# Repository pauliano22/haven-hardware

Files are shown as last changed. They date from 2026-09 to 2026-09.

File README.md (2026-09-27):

# haven-hardware

Hardware design files for Project Haven. All binary CAD/PCB formats
(`.step`, `.stp`, `.stl`, `.epro`, `.xlsx`, `.pdf`, and Altium library files)
are tracked via **Git LFS** — run `git lfs install` once, then clone
normally.

## Layout

- **`openearable_base_pcb/`** — OpenEarable's official PCB exports as
  downloaded from Altium 365: main 2.0, flex 2.0, and a debugging breakout
  1.0. Each folder has schematic/layout PDFs, a BOM, and an `.epro` (Altium
  365 packaged release — open it via Altium 365's viewer or import into
  Altium Designer). No raw `.PcbDoc`/`.SchDoc` source is included upstream.
- **`mechanical_cad/`** — Enclosure CAD. `OpenEarable-Enclosure-2.0.1/` is
  the upstream OpenEarable reference (front/back shells, speaker mount,
  battery mount, `.step` + `.stl`). `Enclosure.stp` is Haven's own enclosure
  design.
- **`haven_dev_board/`** — Haven's own stripped-down custom dev board.
  `component_libraries/` holds Ultra Librarian Altium parts (symbol +
  footprint + 3D model) for the ADAU1860 DSP and the SPH0645LM4H-B MEMS mic.
  **Mic caveat (2026-09-10):** the SPH0645LM4H-B is an *I2S* microphone. On
  the OpenEarable-derived board the mic (SPH0641LU4H-1) is a *PDM* part wired
  straight into the ADAU1860's DMIC pins (netlist: U13 → `PDMCLK`/`PDMDIN` →
  U15 C4/C5), and the codec — not the nRF5340 — owns the mic → DSP → speaker
  path. A stripped-down dev board that keeps that topology needs a PDM mic
  library part (e.g. SPH0641LU4H-1), not the I2S one here. See
  `haven-dev-board-kicad/HAVEN_HARDWARE_REVIEW.md` §0. The board's own
  Altium project files go directly in `haven_dev_board/` once that design
  exists.

## Why LFS

Every future PCB revision or CAD export is another full binary blob — these
don't diff or merge, so without LFS the repo's `.git` history only grows,
forever, even for teammates who never touch hardware. LFS stores pointers in
git and the actual binaries in a separate store, fetched on demand.

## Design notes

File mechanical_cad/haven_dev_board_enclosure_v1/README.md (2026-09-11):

# Haven dev board enclosure — v1 concept

A first-draft mechanical envelope for a real product-shaped enclosure around
`haven_dev_board_kicad`'s electronics, generated parametrically with
[CadQuery](https://cadquery.readthedocs.io/) (`generate_enclosure.py` — real
code, not a hand-modeled one-off; re-run it to regenerate or tweak
dimensions).

**This is not the same thing as `mechanical_cad/Enclosure.stp`** (the
existing file in the parent folder). That one was built around the stock
3-board OpenEarable stack (main + flex + debugging boards) — it's missing
the ADAU1860 entirely and includes a pressure/IR-temperature/accelerometer
sensor suite that doesn't exist on the actual routed board. This new folder
is scoped to the real, routed `haven_dev_board_kicad` BOM instead.

## Why this shape and size

Not guessed — derived from real numbers:

| Driver | Real spec | Source |
|---|---|---|
| BLE module | MDBT53-1M, 9.3 × 14.3 × 1.85mm, onboard chip antenna | Raytac datasheet |
| Battery | Varta CP1454 A4X, 14.1mm dia × 5.4mm, 108mAh Li-ion rechargeable | Varta CoinPower datasheet — the same cell the (wrong-board) `Enclosure.stp` had already picked, reused here since it's a real, sensible, off-the-shelf choice |
| microSD slot | TF-06A push-push connector, ~12 × 14mm footprint | HAVEN_BOM.csv (`CARD1`) |
| USB-C | GT-USB-9047A SMD receptacle | HAVEN_BOM.csv (`U12`) |
| Reference silhouette | Modern RIC hearing aid body ≈ 8 × 12 × 30mm (Phonak Audéo Paradise) | web search — but Haven's BOM carries far more (a full BLE SoC, IMU, PMIC, fuel gauge, level shifter, USB-C, microSD) than a sleek consumer RIC does, so this is deliberately chunkier than that reference, closer to a rugged/OTC BTE body |

Resulting body: **40 × 19mm footprint, 12mm thick, ~18mm tall including the
ear hook.** Comparable to a mid-range/rugged BTE hearing aid or hearing-
protection electronics form factor — not the sleekest fashion hearing aid,
because the component count genuinely doesn't allow it yet.

## What's actually in this file

- A rounded-capsule two-piece shell (`_top_shell_v1` / `_bottom_shell_v1`,
  split at the vertical midplane) with 1.2mm walls.
- A behind-the-ear hook, built as a torus arc (analytically smooth, not a
  faceted approximation — see the comments in `generate_enclosure.py` for
  why a naive swept-tube approach didn't work). It's **purely mechanical
  retention** — Haven's actual signal path to the ear runs through a
  separate flex/wire to an in-ear receiver, so the hook has no acoustic
  bore, unlike a real hearing aid's sound-tube hook.
- USB-C cutout, microSD slot cutout, a mic acoustic port, an LED window, and
  a cable exit for the flex/wire to the in-ear receiver+eartip.
- A PCB reference envelope (31 × 13 × 1mm) and the battery envelope, both
  verified — by actual point-in-solid classification against the real
  B-rep, not by eyeballing a render — to fit inside the cavity without
  colliding with the walls or each other.

## A real finding from the fit check, worth knowing before laying out the actual board

The PCB and battery envelopes overlap in footprint (there isn't room to put
them fully side-by-side at this size) and are separated only by stacking in
Z. That means **the real board can't be a plain rectangle** — it needs an
L-shaped or notched outline (or a mounting bracket) to nest around the
battery on the same level, the same way most compact earbuds/hearing aids
handle this. Worth deciding before committing to a board outline, whichever
CAD tool ends up drawing it (Altium or a further KiCad rescale).

## Verified, not assumed

Every cutout and every fit check in this model was confirmed with OCCT's
`BRepClass3d_SolidClassifier` — testing whether specific real-world points
are inside/outside the actual solid — not by eyeballing a rendered preview.
This mattered: an early version's microSD cutout *looked* plausible in a
render but a solid-classification check caught that it had completely
missed the body due to a workplane-normal sign assumption that turned out
to be wrong for that named plane. Re-verify the same way after any
parameter change, especially port positions.

## What this is NOT yet

- **No real ear-fit data.** The hook curvature (5.5mm arc radius) is a
  reasonable generic guess, not fit to any anthropometric ear dataset.
  Real hearing aid manufacturers iterate this against actual ear
  measurements or 3D scans — this hasn't been done here.
- **No snap-fit or screw-boss features** between the top/bottom shells yet
  — right now they're just a flat split, not a manufacturable fastening
  method.
- **No DFM (draft angles, minimum wall thickness for the actual material/
  process) pass** — dimensions assume idealized geometry, not a specific
  injection-molding or SLA process's real constraints.
- **The PCB/battery envelopes are placeholders**, not the actual routed
  board — once a real board outline exists (matching the L-shape/notch
  finding above), re-run the fit check against its real outline, not this
  simple rectangle.

## Files

- `haven_enclosure_assembled_v1.step` — full shell (both halves fused), for
  viewing/reference.
- `haven_enclosure_top_shell_v1.step`, `haven_enclosure_bottom_shell_v1.step`
  — the two actual printable/moldable parts.
- `generate_enclosure.py` — the CadQuery source. All dimensions are named
  constants at the top; re-run after editing to regenerate the STEP files.
- `preview_iso.png`, `preview_internal_fit_check.png` — renders.

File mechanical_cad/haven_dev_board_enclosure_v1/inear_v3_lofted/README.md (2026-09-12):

# Organic lofted shape (v3)

Supersedes `inear_v2/` as the current direction, per feedback that v2's
straight elliptical capsule "doesn't look great" for something meant to
read as a real earbud. v2 kept for reference, not deleted.

## Shape

Built with `cq.Workplane.loft()` across six elliptical stations (see
`stations` in `generate_inear_enclosure_v3.py`) instead of a single
straight-extruded ellipse: a rounded, dome-topped "head" (where the
electronics live) that tapers down through a narrowing "neck" into a
canal stalk, with each station's center offset slightly further in one
direction than the last — that's what gives the body its forward lean,
rather than running as a straight vertical column.

Checked Apple's own public dimensional drawing for AirPods Pro (2nd
generation) — available at developer.apple.com/accessories/
dimensional-drawings/ for accessory makers — for proportion *language*
(a rounded head, a stem/neck that leans relative to it, roughly how much
taller the head-to-tip run is than the head is wide). That drawing is
licensed only for making accessories that fit around the real product,
not for cloning its form, so this shape's actual dimensions, curvature,
and proportions are our own, not traced from it.

## A real sizing correction this pass caught

The widest single cross-section on this new lofted body is only
~17 × 14mm. v2's PCB placeholder was 29mm long — sized for the old
straight-capsule shape and never rechecked here — and would not fit
anywhere on this body at all. The real limiting component is the
MDBT53-1M module (9.3 × 14.3mm, the single biggest part in the BOM);
everything else is under 3 × 3mm plus small passives. A compact
**16 × 13mm** board holds all of it, and that's what's modeled and
fit-checked in this version instead. Worth keeping in mind for whoever
lays out the real board: it needs to be genuinely compact, not just
"smaller than the case."

## Bug found and fixed: the two-part split was bogus

The original shell split (`top_half` = everything above `z=-20`,
`bottom_half` = the remainder) was carried over from the earlier BTE
enclosure, where a horizontal split made sense for that shape's
orientation. It doesn't for this one: this body is a tall, mostly-vertical
loft (head at z≈17 down to the nozzle base at z≈-14.5), so a Z-height cut
put **99% of the volume in "top" and the leftover 1% sliver in "bottom"**
(1820 mm³ vs 19 mm³, confirmed by importing both STEPs and comparing
`.Volume()` directly — not something a render alone would necessarily
flag, since "top" alone silhouettes like a complete shell). Not a
two-part enclosure by any usable definition.

Fixed by splitting through the tube's long axis instead — an `X=0` plane,
giving left/right halves that both run the full head-to-nozzle length.
Re-verified by volume: **917.4 mm³ vs 921.6 mm³ (1.00x ratio)**. All the
existing port/PCB/battery checks were re-run against the corrected split
and still pass. Files renamed `..._left_v3.step` / `..._right_v3.step` to
describe what they actually are now, replacing the old (deleted)
`..._top_v3.step` / `..._bottom_v3.step`.

## Verification

Same discipline as v2: every port cut is verified by scanning many points
across it for a genuine hole (not trusting one computed coordinate — this
body has no flat faces at fixed offsets, so that would fail the same way
a plain point-check did on v2's curved surface), and the PCB/battery
envelopes are checked point-by-point against the real solid geometry for
collisions. All pass with 0 collisions found.

## Alignment pegs across the seam

Added two locating pegs (1.2mm radius, 1.6mm-radius clearance socket) to
register the left/right halves during assembly. Finding worth recording:
the X=0 split plane only has real touching wall material near the front/
back edges of a given cross-section — through the middle of a wide
station (e.g. the head, z~12-17) the two halves face an open hollow
cavity across the seam, not each other, since the split cuts through the
ellipse's interior, not its wall. Confirmed by direct point-classification
(scanning along x at fixed y/z), not assumed. The pegs sit near the top of
the head (z≈15.5) at the ellipse's front and back edges (y≈±5.0), where a
scan confirmed solid material spans the seam — a wide baseline that
resists rotation, not just translation, between the two halves. Each site
is verified for peg presence, socket clearance, and that the socket
doesn't cut past the original wall's outer surface.

## Still open

Same caveats as the earlier versions: no real ear-fit/anthropometric data,
no DFM pass,
placeholder PCB/battery envelopes (not the real routed board outline —
still needs the L-shaped/notched consideration from the BTE version's
findings once a real board layout exists). Also still open: whether
USB-C/microSD belong on the in-ear piece itself or should move to a
charging case in a later hardware revision (most true wireless earbuds
put them on the case).

## Files

- `haven_enclosure_inear_assembled_v3.step` — full shell, for viewing.
- `haven_enclosure_inear_left_v3.step`, `haven_enclosure_inear_right_v3.step`
  — the two actual printable/moldable parts.
- `generate_inear_enclosure_v3.py` — CadQuery source; the `stations` list
  at the top defines the whole silhouette.
- `preview_iso.png`, `preview_internal_fit_check.png` — renders.

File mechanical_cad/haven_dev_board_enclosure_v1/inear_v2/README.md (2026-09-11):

# In-ear pivot (v2)

Supersedes the behind-the-ear (BTE) design in the parent folder as the
current direction, per an explicit request to make the enclosure actually
sit in the ear rather than hang behind it. The BTE version is kept as-is
for reference, not deleted.

## Shape

A genuinely oval body (elliptical cross-section via `cq.Workplane.ellipse`,
not a rounded rectangle that just reads as a cylinder from most angles),
sized in the same family as a single AirPods Pro earbud body (30.9 × 21.8 ×
24mm, real spec) — this design runs to 20 × 23 × 33mm, similar volume,
because Haven's BOM carries more electronics (full BLE SoC, IMU, PMIC, fuel
gauge, level shifter, USB-C, microSD) than a sleek consumer earbud does.

A canal stalk (5.4mm diameter, mid-range of the real 4–6mm eartip-stem
spec found via web search) protrudes from the bottom, tilted 18° forward,
with a small retention barb near the tip so a standard silicone eartip has
something to grip rather than sliding off a plain cylinder. No BTE hook —
this design relies on the eartip's fit and grip to stay in, like a real
earbud or a modern RIC hearing aid.

## A real modeling lesson from this pivot

The BTE version's ports were positioned by computing an offset from a flat
box face (`BODY_W/2 - port_size/2 - wall`, etc.) — that works cleanly for
a box, but this body's outer surface is an ellipse with a filleted cap, so
the true surface position isn't a fixed offset; it varies with height and
tapers hard near the caps. An early attempt reused the box-style offset
math and several ports missed the body entirely (their location, per the
same formula, was floating past a corner that no longer existed in the new
shape). Fixed by verifying with a *scan* — testing many points across a
range for each cut, confirming a hole genuinely exists somewhere on that
line — rather than trusting a single computed point. Every port and the
nozzle bore are verified this way now (see the `scan()` helper and the
per-feature checks at the bottom of `generate_inear_enclosure.py`).

## Real, unusual-for-a-tiny-earbud detail worth a conscious decision

Most true wireless earbuds keep USB-C and any storage slot on the charging
*case*, not the earbud itself (the earbud usually only has charging
contacts). This design puts a real USB-C receptacle and a full microSD
slot directly on the in-ear body, because that's what the actual routed
`haven_dev_board_kicad` BOM has. It fits here — verified, not assumed —
but it's worth deciding consciously whether a later hardware revision
should move user-accessible USB-C/microSD to a case instead.

## Still open (same caveats as the BTE version)

No real ear-fit/anthropometric data behind the body or canal-stalk
dimensions, no snap-fit/screw-boss features between the two shell halves,
no DFM pass, and the PCB/battery envelopes are still placeholders (not the
actual routed board outline — see the BTE README for the L-shape/notch
finding, which applies here too).

## Files

- `haven_enclosure_inear_assembled_v2.step` — full shell, for viewing.
- `haven_enclosure_inear_top_v2.step`, `haven_enclosure_inear_bottom_v2.step`
  — the two actual printable/moldable parts.
- `generate_inear_enclosure.py` — CadQuery source, all dimensions as named
  constants at the top.
- `preview_iso.png`, `preview_internal_fit_check.png` — renders.

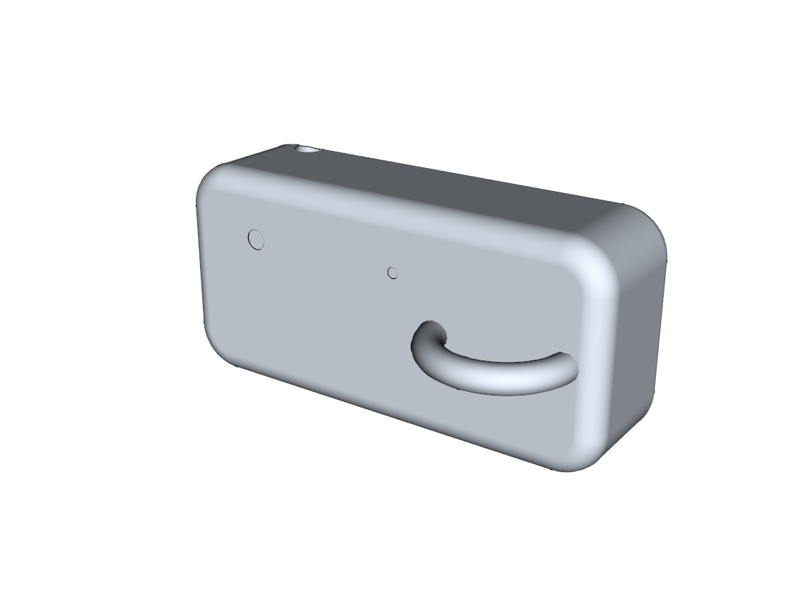
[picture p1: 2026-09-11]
mechanical_cad/haven_dev_board_enclosure_v1/preview_iso.png

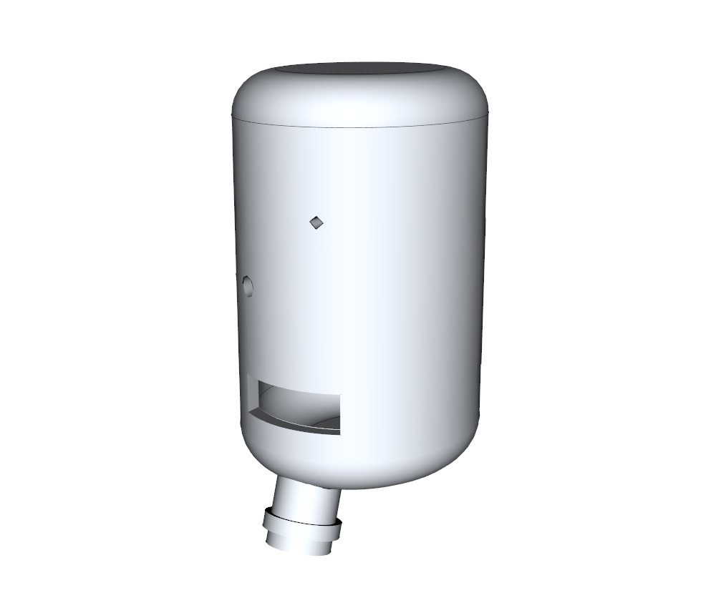
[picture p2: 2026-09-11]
mechanical_cad/haven_dev_board_enclosure_v1/inear_v2/preview_iso.png

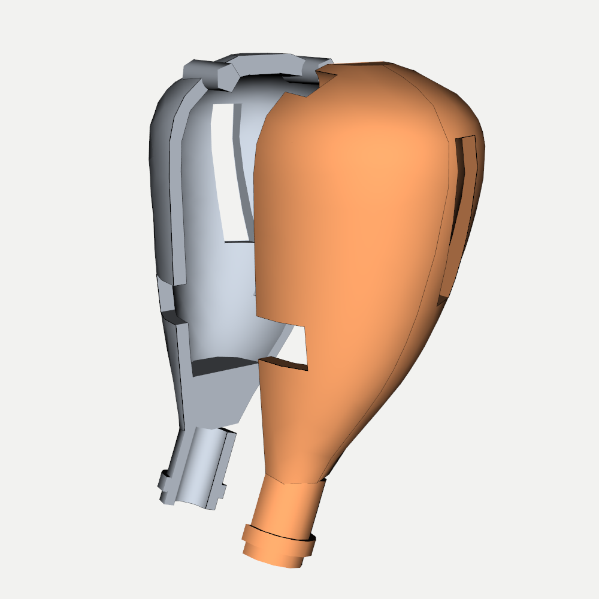
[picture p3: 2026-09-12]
mechanical_cad/haven_dev_board_enclosure_v1/inear_v3_lofted/preview_internal_fit_check.png

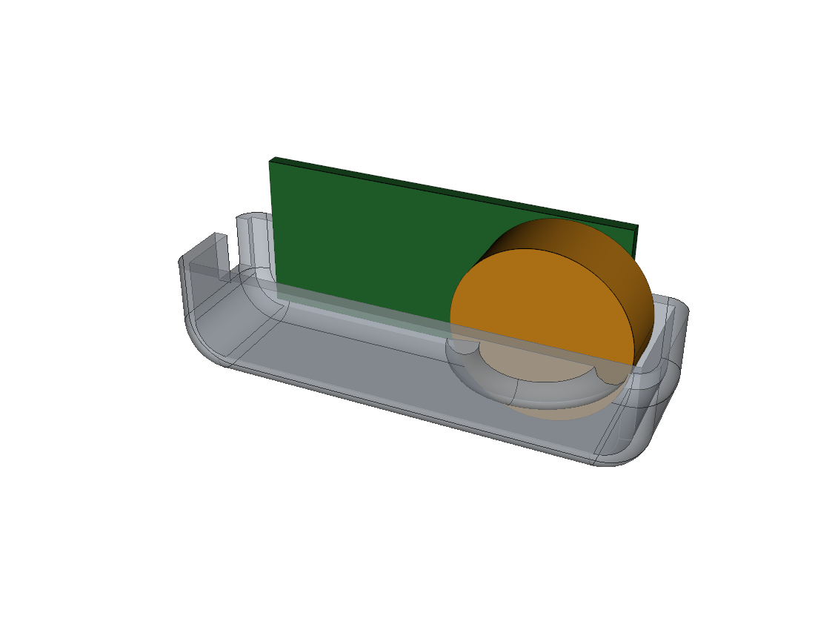
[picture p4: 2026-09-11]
mechanical_cad/haven_dev_board_enclosure_v1/preview_internal_fit_check.png

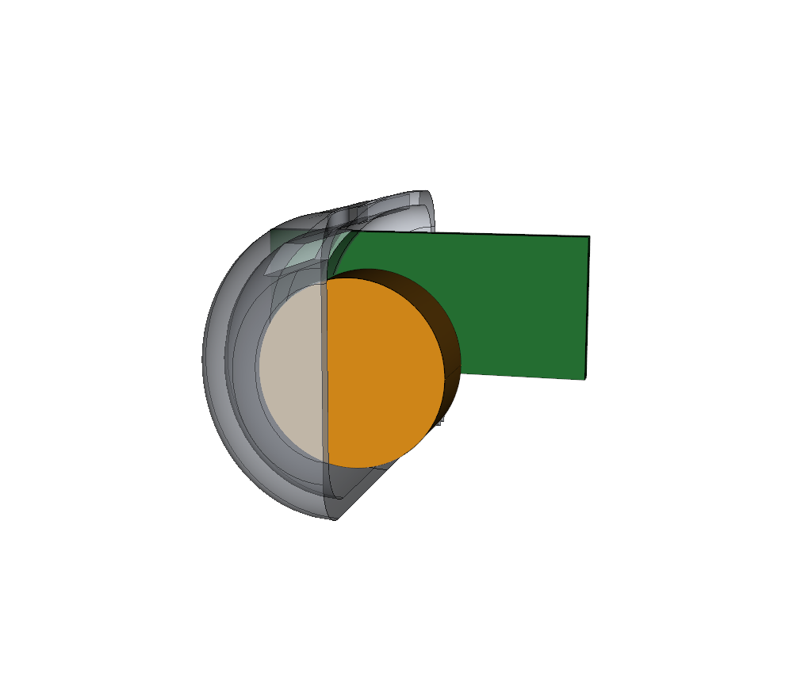
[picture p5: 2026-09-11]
mechanical_cad/haven_dev_board_enclosure_v1/inear_v2/preview_internal_fit_check.png

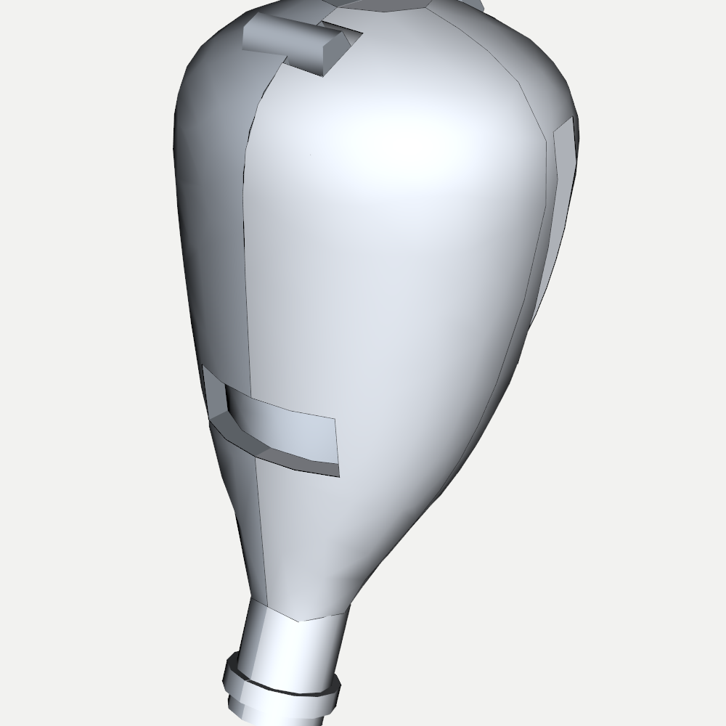
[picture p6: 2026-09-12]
mechanical_cad/haven_dev_board_enclosure_v1/inear_v3_lofted/preview_iso.png

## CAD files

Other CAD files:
mechanical_cad/haven_dev_board_enclosure_v1/inear_v2/haven_enclosure_inear_assembled_v2.step
mechanical_cad/haven_dev_board_enclosure_v1/inear_v3_lofted/haven_enclosure_inear_assembled_v3.step
mechanical_cad/haven_dev_board_enclosure_v1/haven_enclosure_assembled_v1.step
haven_dev_board/component_libraries/ul_ADAU1860-1BCBZRL/Altium/ADAU1860-1BCBZRL/CB-56-6_ADI.step
mechanical_cad/Enclosure.stp
mechanical_cad/haven_dev_board_enclosure_v1/fit_test_prints/haven_fit_test_L.stl
mechanical_cad/haven_dev_board_enclosure_v1/haven_enclosure_top_shell_v1.step
mechanical_cad/OpenEarable-Enclosure-2.0.1/OpenEarable-front-2.0.0.stl
mechanical_cad/haven_dev_board_enclosure_v1/fit_test_prints/haven_fit_test_S.stl
mechanical_cad/haven_dev_board_enclosure_v1/haven_enclosure_bottom_shell_v1.step
mechanical_cad/haven_dev_board_enclosure_v1/inear_v2/haven_enclosure_inear_top_v2.step
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

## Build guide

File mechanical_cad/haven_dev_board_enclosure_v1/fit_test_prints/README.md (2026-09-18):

# Fit-test prints (empty shells - no electronics)

Purpose: find out by trying it in an ear, not by guessing, whether the v3
outer shape is comfortable and stable, BEFORE anyone designs a final board
around it. Three uniform scales of the same v3 shape:

| File | Size (mm) | Nozzle |
|---|---|---|
| haven_fit_test_S.stl | 19.7 x 18.1 x 35.2 | 4.9 mm |
| haven_fit_test_M.stl | 21.9 x 20.1 x 39.1 | 5.4 mm |
| haven_fit_test_L.stl | 24.0 x 22.1 x 43.0 | 5.9 mm |

## How to print
Cornell RPL offers free 3D printing (see HARDWARE_COST_ALTERNATIVES.md).
Resin (SLA) gives a smooth, comfortable surface; FDM works if sanded.
Add a soft silicone/foam ear tip on the nozzle - do not push a hard nozzle
into the canal. This is a fit mock, not a functional or acoustic prototype.

## What to record (each size, each ear if possible)
- Does it stay in with head movement / chewing / jogging?
- Pressure points (concha, tragus, antitragus, canal entrance)?
- Comfort at 15 min and 1 hour.
- Does the head protrude much? (Photo from front and side.)
- Nozzle: too tight, too loose?

## Reference numbers this was checked against
Ear-canal length ~31 mm avg; entrance ~6-9 mm wide x 8.5-12.5 mm tall;
narrowest point (isthmus) ~5.7 mm wide x ~9 mm tall; housings that fit inside
the concha are ~11-16 mm wide; concha-back-wall to canal ~15-20 mm.
Sources: CT ear-canal geometry study (PMC10219681), Hearing Health &
Technology Matters concha/canal series. The v3 head (~21 x 18 mm) is larger
than the concha cavity, so it sits partly outside the ear - expected, but the
fit test is what says whether it is acceptable.

## What sets the minimum size (why this may not shrink much yet)
- Radio module MDBT53: 9.3 x 14.3 mm (largest part).
- Battery in the model: 14.1 mm coin cell. A smaller pouch cell or a bare
  nRF5340 chip (custom RF design) are the real routes to a smaller head -
  both are later-revision work, after the dev board proves the chips work.

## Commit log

2026-08-06 Initial hardware assets: OpenEarable PCB exports, mechanical CAD, dev board component libraries
    - openearable_base_pcb/: main-2.0, flex-2.0, debugging-1.0 (Altium 365
    exports — schematic/layout PDFs, BOM, .epro release packages)
    - mechanical_cad/: OpenEarable reference enclosure 2.0.1 (.step/.stl) plus
    Haven's own Enclosure.stp
    - haven_dev_board/component_libraries/: Ultra Librarian Altium parts for
    the ADAU1860 DSP and SPH0645LM4H-B mic used on Haven's custom board
    - Git LFS tracks all binary CAD/PCB/library formats
    Claude-Session: https://claude.ai/code/session_01XaTzUrQ3v7iAZFe47RtYoq
    [ADAU1860-1BCBZRL.PcbLib, ADAU1860-1BCBZRL.SchLib, CB-56-6_ADI.step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]
2026-09-11 README: flag SPH0645 (I2S) vs the board's actual PDM mic topology
    The component library here is for an I2S mic, but on the OpenEarable-derived
    board the mic is PDM into the ADAU1860's DMIC pins and the codec owns the
    whole audio path. Point at the cross-check in haven-dev-board-kicad.
    Claude-Session: https://claude.ai/code/session_01K7G9Bv5agmyedmt776NSLV
2026-09-11 Add v1 enclosure concept scoped to the actual routed dev board
    The existing Enclosure.stp was built around the stock 3-board OpenEarable
    stack (confirmed by cross-referencing its ~116 parts against the real
    haven_dev_board_kicad BOM) -- it's missing the ADAU1860 entirely and
    carries a pressure/IR-temp/accelerometer sensor suite that doesn't exist
    on the actual board. This is a new, separate concept scoped to the real
    component list instead, not a replacement for the old file.
    Sized from real component specs (Raytac MDBT53-1M datasheet, Varta
    CP1454 A4X datasheet, the actual BOM's microSD/USB-C footprints) against
    a real hearing-aid-form-factor reference, not guessed. Parametric
    CadQuery sou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
    [haven_enclosure_assembled_v1.step, haven_enclosure_bottom_shell_v1.step, haven_enclosure_top_shell_v1.step]
2026-09-11 Pivot enclosure to an in-ear (concha + canal stalk) shape
    Explicit request to make the device actually go in the ear rather than
    hang behind it on a hook. New sibling design (inear_v2/), BTE version
    kept for reference, not deleted.
    Genuinely oval body (elliptical cross-section, not a rounded box) sized
    against a real reference (AirPods Pro single-earbud body, 30.9x21.8x24mm)
    -- similar volume, since Haven's BOM carries more electronics than a
    sleek consumer earbud does. Canal stalk sized to the real 4-6mm eartip
    nozzle spec, with a retention barb.
    Real lesson from this pivot: box-face offset math for port placement
    doesn't carry over to a curved, capped body -- an early attempt missed
    seve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
    [haven_enclosure_inear_assembled_v2.step, haven_enclosure_inear_bottom_v2.step, haven_enclosure_inear_top_v2.step]
2026-09-11 Reshape enclosure as a lofted organic earbud form, not a straight capsule
    Feedback: the previous in-ear version (a straight elliptical extrusion)
    "doesn't look great" -- doesn't read as a real product shape. Rebuilt as
    a genuine loft across six elliptical stations with progressively offset
    centers, giving a rounded head that tapers into a leaning neck and canal
    stalk, the same general shape language real earbuds use (checked Apple's
    public AirPods Pro dimensional drawing for proportion language only --
    that document is licensed for accessory-fitting, not for cloning the
    form -- this shape's actual dimensions and curvature are our own).
    Real correction this pass forced: the new body's widest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
    [haven_enclosure_inear_assembled_v3.step, haven_enclosure_inear_bottom_v3.step, haven_enclosure_inear_top_v3.step]
2026-09-11 Fix v3 enclosure's bogus top/bottom shell split
    The Z-height split (carried over from the earlier BTE design) put 99%
    of the body's volume in one piece and a ~1% sliver in the other --
    confirmed by comparing .Volume() on the exported STEPs (1820mm3 vs
    19mm3), not obvious from the renders since the sliver's silhouette
    still looked like a complete shell. This body is a tall vertical loft,
    so a horizontal cut just slices off the tip.
    Switched to an X=0 split through the tube's long axis instead, giving
    left/right halves that both run the full head-to-nozzle length:
    917.4mm3 vs 921.6mm3 (1.00x). All existing port/PCB/battery fit checks
    re-run clean against the corrected geometry.
    Co-Authored-B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
    [haven_enclosure_inear_assembled_v3.step, haven_enclosure_inear_bottom_v3.step, haven_enclosure_inear_left_v3.step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]
2026-09-12 Add alignment pegs across the enclosure's left/right seam
    First real progress on the "no snap-fit/screw-boss features" item that's
    been listed as open since v1. Two locating pegs (1.2mm peg, 1.6mm
    clearance socket) near the top of the head at the ellipse's front/back
    edges, where the seam actually has touching wall material.
    Real finding along the way: through a wide cross-section (the head,
    z~12-17) the X=0 split plane passes through open hollow cavity, not
    facing wall material -- the two halves only truly meet near each
    station's front/back edges, where the ellipse boundary itself crosses
    x=0. Found by point-classification scanning, not assumed; an initial
    placement guess at the ellipse's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
    [haven_enclosure_inear_assembled_v3.step, haven_enclosure_inear_left_v3.step, haven_enclosure_inear_right_v3.step]
2026-09-18 Add printable fit-test shells (S/M/L) with a comfort-test protocol
    Empty scaled copies of the v3 shell to test fit in a real ear before
    any final board is designed around it. Checked against published ear
    canal/concha dimensions; notes the v3 head is larger than the concha
    cavity, and what actually limits miniaturization (radio module, battery).
    Claude-Session: https://claude.ai/code/session_01YTbrWH9Gt2quSDLgz6Te5V
    [haven_fit_test_L.stl, haven_fit_test_M.stl, haven_fit_test_S.stl]
2026-10-29 Add the Rev A front shell with a standard ear-tip nozzle; fix fit-test nozzles
    Rev A uses OpenEarable 2.0.1's enclosure. Its oval stem only takes
    OpenEarable's own tips, so the generator replaces it with a round 5.4 mm
    nozzle (6.2 mm lip, 3.0 mm bore) on the same axis, which takes common
    4.5 mm-bore foam and silicone tips. It also closes the sensor-flex window
    with a skin that follows the head's dome, since Rev A drops the flex board.
    Checks in the generator confirm the bore is open to the speaker cavity, the
    walls are solid, the skin is flush, and nothing collides with the speaker
    mount.
    The S/M/L fit-test prints scaled the nozzle with the body (4.9/5.4/5.9 mm).
    Ear-canal size is handled b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
2026-10-29 Add the Rev B fit study: compact earbud and charging case
    Places real part envelopes (CP1254 cell, 8 mm driver, MDBT53V-1M or
    ISP2053 module on a 0.8 mm board, SPH0641 mic, magnet, two charging pads)
    in the smallest shell that keeps 0.3 mm to every wall, with the Rev A
    nozzle and no vent. Head comes out 16.7 x 18.9 x 17.5 mm, about 40%
    smaller than Rev A's shell; the battery, not the module, sets the
    footprint. Case concept for two buds is 53.5 x 45.5 x 25.5 mm. Picks a
    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
2026-10-30 Add v2 ergonomic shell, scored against six scanned human ears
    The fit-study bud read as a cube that could fall out. This builds organic
    in-concha bodies around the same v2 internals (implicit-surface shell:
    part distance fields offset, closed, smoothed and hollowed to a uniform
    1.1 mm wall, with the standard nozzle and no vent) in two layouts, and
    seats each one in six right ears from the HUTUBS database (TU Berlin,
    CC BY 4.0) spanning concha width 11.4-21.6 mm, against the old block.
    The stacked layout (battery just outside the driver, board outermost)
    halves the block's tissue interference (mean area pressed >1 mm 323 vs
    711 mm2, worst compression 4.5 vs 5.7 mm) at equal contact and
    protr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
2026-10-30 Add a smaller v2 shell variant (CP0854 + 6 mm driver) with its fit results
    HAVEN_VARIANT=small builds the stacked layout around a VARTA CP0854 cell and a
    6 mm driver, writing _small outputs next to the current design's files.
    evaluate_fit.py can now run named jobs and merge them into fit_results.json.
    In six HUTUBS ears the smaller bud is 1 g lighter and 3 mm shallower, sits
    2 mm lower on average, but is not shorter (the board sets the length) and
    still compresses the smallest ear by ~4.6 mm. For comparison only; the
    current parts stay.
    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
2026-10-30 Add v2 form-factor concepts scored in six scanned ears
    Compares shapes with Paul's fixed parts (CP1254-or-better battery life,
    8 mm driver, MDBT53V-1M, ADAU1860, SPH0641): a stem with a cylindrical
    cell (GP1018L10, 100 mAh), an AirPods-Pro-style stem with the CP1254 in
    the head, bean + wing (the nestled layout, reused), and a behind-the-ear
    receiver-in-canal design. The stacked pebble stays the best earbud shape;
    the cell-in-stem bud is heavier and levers out; the BTE in-ear unit
    presses least but needs a visible pod and a cable. No concept has less
    battery life than the current design. The pod's groove fit ran on
    cropped scans and is marked unreliable.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
2026-11-04 Smooth the cell-in-head stem shell (closing radius 5.5 mm)
    The 3.5 mm closing radius left lumps around each part. 5.5 mm fills the
    notches between head, battery and stem so it reads as one smooth form;
    envelope unchanged (19.4 x 33.0 x 22.1 mm), all parts still >= 0.48 mm
    clearance. The six-ear fit numbers in the README are from the previous
    shell and were not re-run (the scans weren't available this session).
2026-11-04 Add v2 behind-the-ear mechanics: in-ear units A/B, pod, cable route, board outlines
    Pod 19.5x33.2x11.4 mm (5.4 g) with a 13x27 mm board outline; in-ear unit A
    (mic in ear) 13.7x15.8x17.6 mm, 1.6 g; B (speaker only) as fallback. Scored
    on six HUTUBS heads: pod <0.5 mm compression everywhere, in-ear 2.2-3.9 mm
    (needs another pass or S/M/L sizes), cable 46-56 mm over the helix root.
2026-11-04 BTE in-ear A: bottom-port mic under the board, refit on six heads
    The SPH0641LU4H-1 is bottom-port, so it moves to the board's driver side and
    hears through a plated hole that lines up with the shell's mic hole. Unit A
    grows 1 mm (18.6 mm), worst-ear compression 3.9 -> 4.4 mm, mean area 199 ->
    201 mm2; cable 43-57 mm. Adds refit_inear_A.py.
2026-11-05 v2 BTE charging case: base, lid, plate, board outline; pods drop into their own envelope
2026-11-05 Case: deeper pocket for the battery and pin margins, USB-C at x=-2, LED light hole
2026-11-05 Case: decimate exported meshes to 150k faces (still watertight) to keep LFS small
2026-11-05 Case: spring pin working height is a parameter (10.0 mm for the KH-PG2011005-DZ candidate)
2026-11-05 Case: decimate with repair so base and lid stay watertight and small
2026-11-05 In-ear unit reshaped (body 3 mm up, 8.5 mm nozzle) + S/M/L comfort sleeves
    Mean worst press on the six HUTUBS ears 3.35 -> 1.77 mm, area > 1 mm 201 -> 46 mm2, from a
    6-offset sweep. Sleeves M/L (0.8/1.5 mm soft band) score worse on all six scans (all S ears);
    kept for larger ears and the real-ear test.
2026-11-06 v2_bte: HAVEN_DRIVER / HAVEN_OUT overrides for swapping the speaker
    BODY_UP now clamps to driver radius - 1.5 so the nozzle bore still faces a smaller driver.
    Default (9.0 x 4.5) output is unchanged. 8.0 x 3.9 builds clean (all clearances ok).
    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
2026-11-06 sleeve_M: remesh at 0.1 mm voxels (17 MB -> 4 MB) so it uploads to JLC3DP
    Quadric decimation can't keep the 0.8 mm band watertight, so the mesh was rebuilt with
    sleeves.build() at VOX=0.1 (volume 261.0 -> 259.9 mm3, watertight).
    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
